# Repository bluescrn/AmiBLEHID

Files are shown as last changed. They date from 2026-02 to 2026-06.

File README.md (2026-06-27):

# AmiBLEHID

Work in progress. v0.3 PCB works. v0.4 is experimental+untested.

First prototype, before addition of buttons+LEDs:

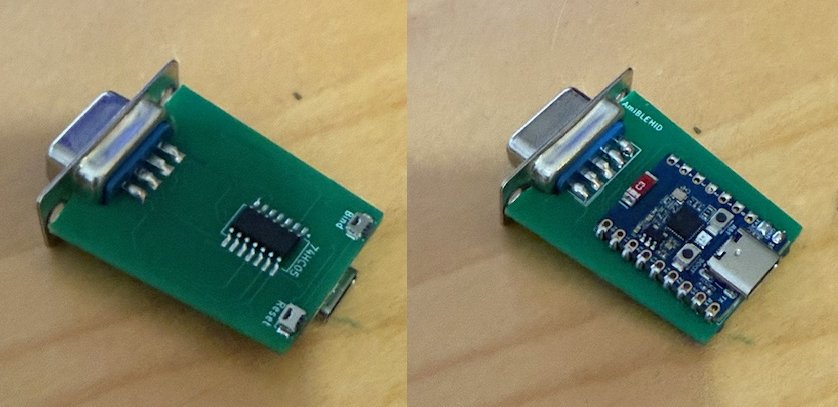
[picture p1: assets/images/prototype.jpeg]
Pic of prototype


## What is it?

With minimal other components (essentially just a 74HC05 and the joystick port connector), an ESP32-H2 module can be connected to an Amiga joystick/mouse port, and allow a BLE mouse or controller to be used with the Amiga.

The H2 has no wifi, and only supports BLE (no Bluetooth Classic). Other ESP32 modules likely draw too much current (With the Waveshare ESP32-H2-Zero and my initial code, I measured 20-23mA with am mouse connected, and 26mA while scanning)

There is an existing project, [Unijoysticle](https://github.com/ricardoquesada/unijoysticle2), that uses an ESP32-WROOM32 and provides compatibility with far more devices by supporting Bluetooth Classic, but it's a relatively bulky board and requires external power. This is an attempt to build a smaller neater 'dongle' using the same approach, albeit with more limited functionality.

## Features

- Mouse speed control (cycle 5 levels via button on board, or hold middle mouse button)
- Mouse emulation using right analog stick when using a controller and Amiga joystick port 1
- 'Up-to-jump' mode - Maps the 2nd button to joystick up

## Code

The code side of things is based around [NimBLE Arduino](https://docs.arduino.cc/libraries/nimble-arduino/) and [this HID report parsing code](https://github.com/pasztorpisti/hid-report-parser), and can be built in the Arduino IDE

Had to add a little bodge to the HID parser to read the hat switch (d-pad) properly, as the neutral position of a hat switch (usually 0 or -1 depending on device) is outside the logical_min/max range of the axis, and the parser was ignoring out-of-range values.

## Limitations

BLE game controllers are very uncommon, the only common+good ones that I'm aware of are the latest model of Xbox controller and the 8BitDo Ultimate Wireless 2.
  
Only supports two joystick/mouse buttons. Investigating

The USB-C port on the ESP32 module isn't currently supported for wired mice/controllers. Would be nice to support wired controllers, but the additional current draw is likely to be too much for the Amiga joystick port

## Tested+Compatible devices

Controllers:
- Xbox Series S/X controller (this is the version with USB-C and the extra 'share' button in the centre. Previous versions aren't BLE)
- 8BitDo Ultimate 2 Wireless

Mice:
- KeyChron M3 Wireless Mouse
- Logitech MX Anywhere 3
- Razer Atheris

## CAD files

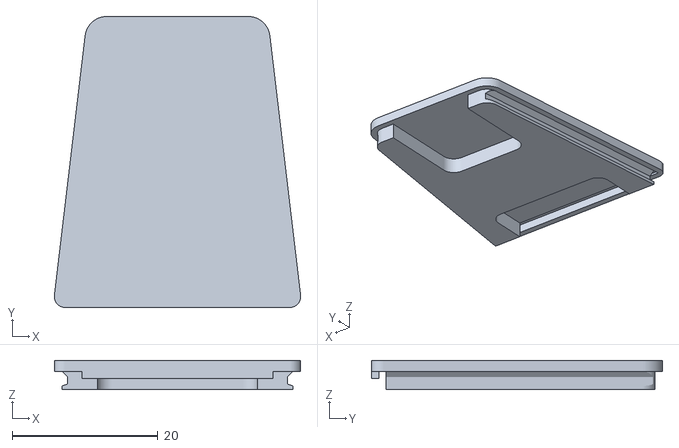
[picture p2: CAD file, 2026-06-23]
STLs/AmiBLEHID_Case_Upper.stl
33.9 x 40.0 x 4.00

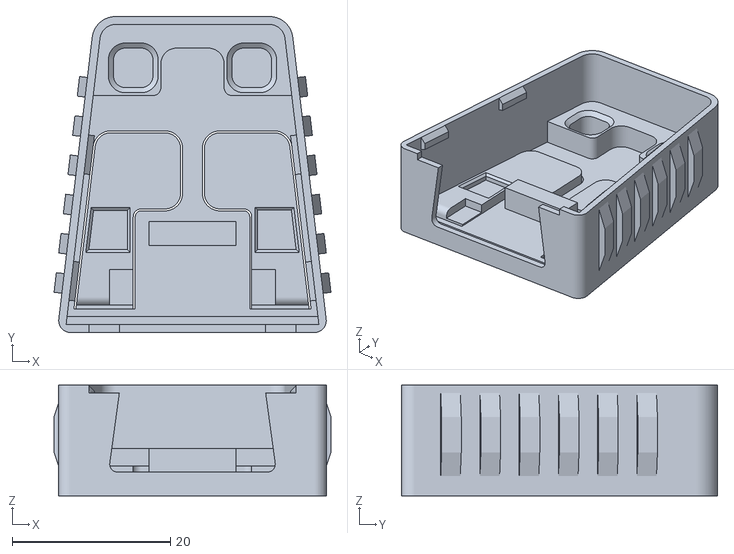
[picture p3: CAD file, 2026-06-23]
STLs/AmiBLEHID_Case_Lower.stl
35.1 x 40.0 x 14.0

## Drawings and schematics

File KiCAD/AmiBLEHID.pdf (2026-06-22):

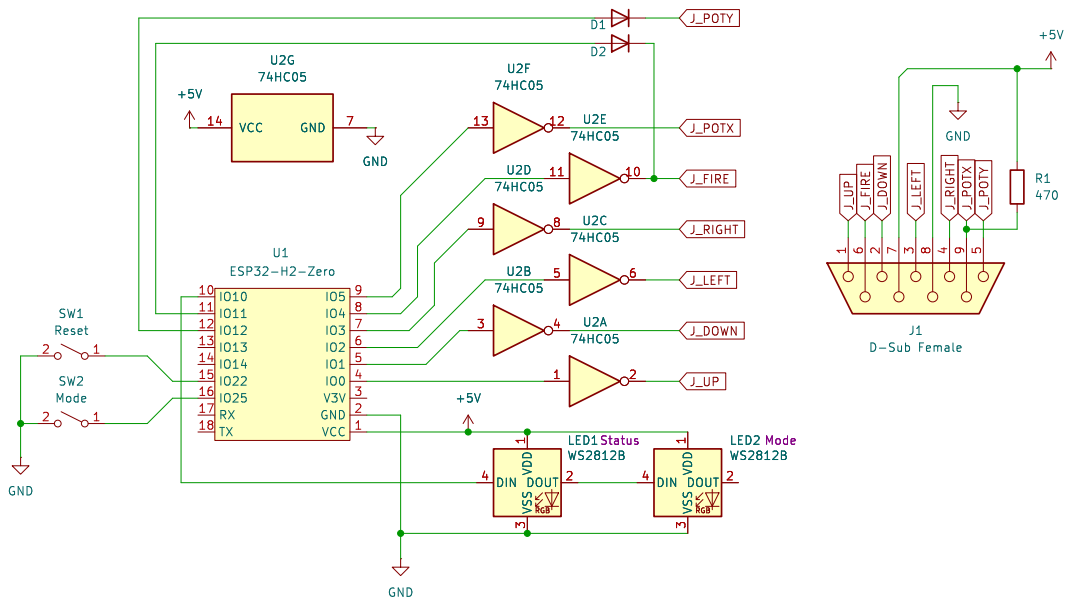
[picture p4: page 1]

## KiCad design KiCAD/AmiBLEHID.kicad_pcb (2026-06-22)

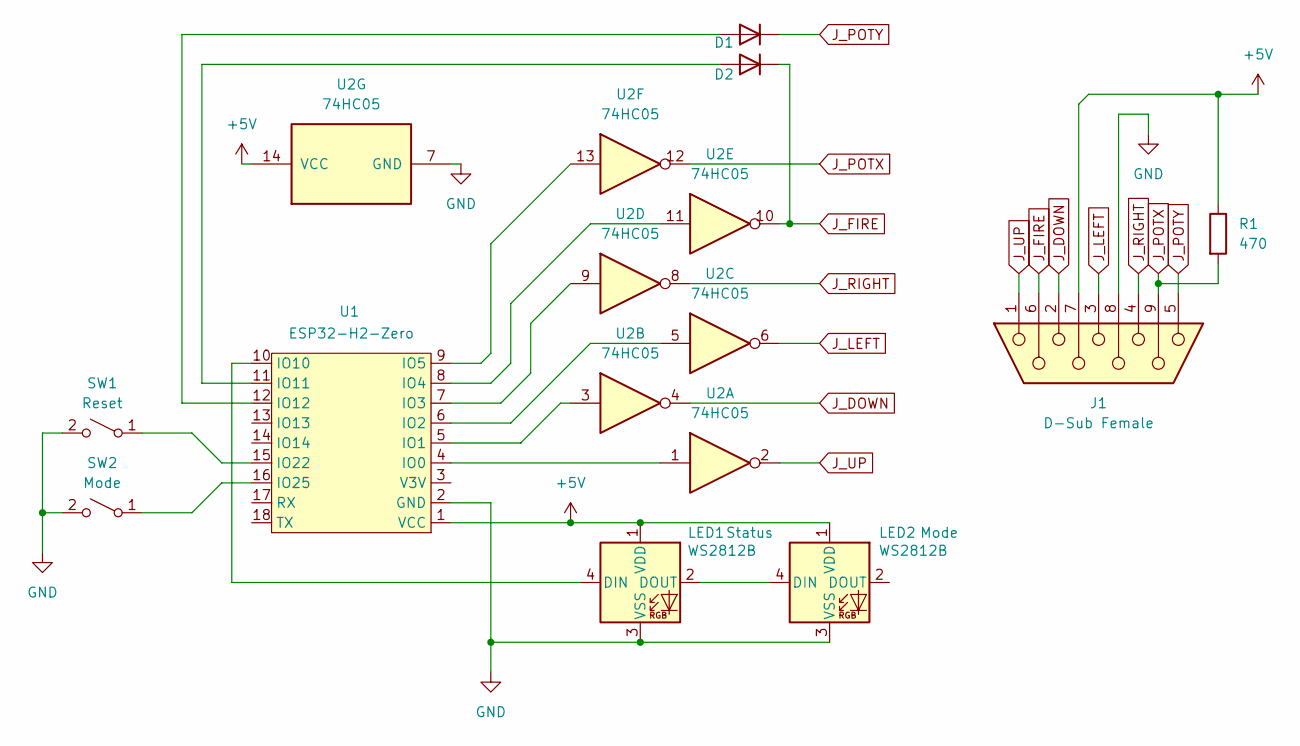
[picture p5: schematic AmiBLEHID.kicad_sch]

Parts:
D1, D2: 1N4148; D_1206_3216Metric
J1: D-Sub Female; DSUB-9_Socket_EdgeMount_P2.77mm
LED1, LED2: WS2812B; LED_WS2812B-Mini_PLCC4_3.5x3.5mm
R1: 470; R_1206_3216Metric
SW1: Reset; SW_SPST_PTS647_Sx50
SW2: Mode; SW_SPST_PTS647_Sx50
U1: ESP32-H2-Zero; Waveshare-ESP32-H2-Zero
U2: 74HC05; SO-14_5.3x10.2mm_P1.27mm

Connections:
+5V: J1.7, LED1.1 (VDD), LED2.1 (VDD), R1.1, U1.1 (VCC), U2.14 (VCC)
GND: J1.8, LED1.3 (VSS), LED2.3 (VSS), SW1.2 (B), SW2.2 (B), U1.2 (GND), U2.7 (GND)
J_DOWN: J1.2, U2.4
J_FIRE: D2.1 (K), J1.6, U2.10
J_LEFT: J1.3, U2.6
J_POTX: J1.9, R1.2, U2.12
J_POTY: D1.1 (K), J1.5
J_RIGHT: J1.4, U2.8
J_UP: J1.1, U2.2
unnamed: D1.2 (A), U1.12 (IO12)
unnamed: D2.2 (A), U1.11 (IO11)
unnamed: LED1.4 (DIN), U1.10 (IO10)
unnamed: LED1.2 (DOUT), LED2.4 (DIN)
unnamed: SW1.1 (A), U1.15 (IO22)
unnamed: SW2.1 (A), U1.16 (IO25)
unnamed: U1.4 (IO0), U2.1
unnamed: U1.5 (IO1), U2.3
unnamed: U1.6 (IO2), U2.5
unnamed: U1.7 (IO3), U2.9
unnamed: U1.8 (IO4), U2.11
unnamed: U1.9 (IO5), U2.13

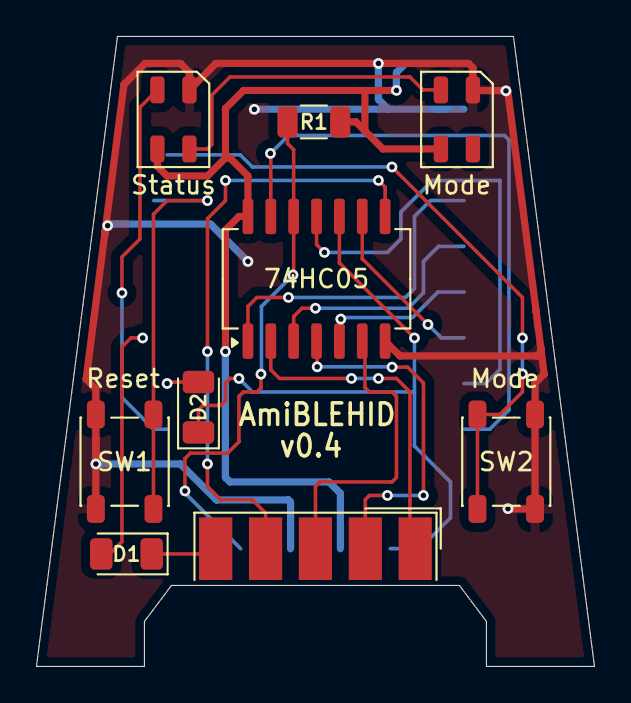
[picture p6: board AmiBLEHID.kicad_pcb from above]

Board: 2 copper layers, 31.0 x 35.0 mm, 10 parts (1 on the bottom side), 21 nets.

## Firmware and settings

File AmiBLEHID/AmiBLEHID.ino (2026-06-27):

// ------------------------------------------------------------------------------------------------------------------------
// AmiBLEHID
// - Connects a Bluetooth mouse or gamepad to Amiga joystick port.
//
// Intended for the WaveShare ESP32-H2-Mini, without outputs to joystick port connected via a 74HC05 open-collector hex inverter
//
// Board should be set to 'ESP32H2 Dev Module'
// Tools -> USB CDC on boot should be enabled to get serial console output
//
// Required libraries/packages:
// - NimBLE-Arduino - works with 2.5.0)
// - FastLED - works with with 3.10.3 (3.10.4 didn't work)
// - Works with esp32 board package 3.3.10
//
// Turn off Sketch->Optimize for debugging. Any performance gain might help with interrupt responsiveness for CD32 support?
// ------------------------------------------------------------------------------------------------------------------------

#define PIN_U           0
#define PIN_D           1
#define PIN_L           2
#define PIN_R           3
#define PIN_A           4
#define PIN_B           5

#define PIN_Y2          0
#define PIN_X1          1
#define PIN_Y1          2
#define PIN_X2          3

#define PIN_CD32_LATCH  12
#define PIN_CD32_CLOCK  11

#define PIN_BTN_RESET   22
#define PIN_BTN_MODE    25

#include <Arduino.h>
#include <NimBLEDevice.h>
#include <BTScan.h>
#include <BTHIDConn.h>
#include <Preferences.h>
#include <LEDs.h>

void IRAM_ATTR onQuadratureTimer();

// ------------------------------------------------------------------------------------------------------------------------
// States
// ------------------------------------------------------------------------------------------------------------------------

#define ANALOG_STICK_DEADZONE 64                // Analog sticks are scaled to a +/-256 range. Big deadzone/threshold when using for digital input
#define MOUSE_STICK_DEADZONE  40                // Smaller deadzone when using it for mouse

#define NUM_MOUSE_RATES       5

const int k_mouseRates[NUM_MOUSE_RATES] = {48, 64, 96, 160, 224};
const int k_defaultMouseRateIdx = 1;

const int k_hardResetHoldTime   = 140 * 3;      // works out at approx 3 secs. 

// ------------------------------------------------------------------------------------------------------------------------
// States
// ------------------------------------------------------------------------------------------------------------------------

enum State 
{
    State_Init,           // Initialising
    State_Scanning,       // Scanning for devices
    State_Connecting,     // Connecting
    State_Connected,      // Connected to a HID device
    State_Idle            // Scan timed out, no device found (wait for button to rescan)
};

enum GamepadMode
{
    Default,
    UpToJump,
    Invalid    
};


// ------------------------------------------------------------------------------------------------------------------------
// Main vars
// ------------------------------------------------------------------------------------------------------------------------

Preferences     _preferences;
BTScan*         _btScan                  = nullptr;
BTHIDConn*      _btHIDConn               = nullptr;
State           _state                   = State_Init;
int             _scanDuration            = 60*1000;

hw_timer_t     *_quadratureTimer         = NULL;
bool            _quadratureTimerStarted  = false;

int             _currMouseRateIdx        = 0;
GamepadMode     _currGamepadMode         = GamepadMode::Default;

LEDs            _statusLeds;
int             _resetHeldTimer          = 0;

volatile bool   _cd32Polling             = false;
volatile int    _cd32ButtonShiftRegister = 0;
volatile int    _cd32buttonState         = 0;
volatile int    _cd32ticksSincePolled    = 0;

int             _mouseDeltaX             = 0;
int             _mouseDeltaY             = 0;
int             _mouseRateX              = 0;
int             _mouseRateY              = 0;
int             _clampedMouseRateX       = 0;
int             _clampedMouseRateY       = 0;
int             _mouseQuadX              = 0;
int             _mouseQuadY              = 0;
int             _numQuadratureTicks      = 0;

const uint8_t   _quad0[4]                = {0,1,1,0};
const uint8_t   _quad1[4]                = {0,0,1,1};
const int       _quadCounterShiftDown    = 12;

// ------------------------------------------------------------------------------------------------------------------------
// Main setup function
// ------------------------------------------------------------------------------------------------------------------------

void setup ()
{    
    // Attempting to run the timer at much more than 6KHz causes it to break
    //
    // This corresponds to about 120 output state changes per frame at 50hz, and apparently the Amiga uses an internal 
    // counter with a limit of 128 counts per frame. I thought a 'count' would require a full pulse, but maybe it's a
    // state change, any of the four quadrature phases?
    
    _quadratureTimer = timerBegin(6000);
    timerAttachInterrupt(_quadratureTimer, &onQuadratureTimer);
    timerAlarm(_quadratureTimer, 1, true, 0);
    timerStart(_quadratureTimer);
    _quadratureTimerStarted = true;
    
    pinMode( PIN_U, OUTPUT );
    pinMode( PIN_D, OUTPUT );
    pinMode( PIN_L, OUTPUT );
    pinMode( PIN_R, OUTPUT );
    pinMode( PIN_A, OUTPUT );
    pinMode( PIN_B, OUTPUT );

    pinMode( PIN_BTN_RESET, INPUT_PULLUP );
    pinMode( PIN_BTN_MODE,  INPUT_PULLUP );

    pinMode( PIN_CD32_LATCH, INPUT_PULLUP );
    pinMode( PIN_CD32_CLOCK, INPUT_PULLUP );

    setupInterrupts();
    
    zeroOutputs();

    Serial.begin(115200);
    
    delay(500);

    _statusLeds.init();

    // Give serial monitor a chance to connect
    delayWithLEDUpdates( 1000 );
    
    Serial.println("");
    Serial.println("");
    Serial.println("");
    Serial.println("----------------------------------------");
    Serial.println("AmiBLEHID");
    Serial.println("----------------------------------------");
    loadSettings();
    Serial.println("Starting NimBLE Client");    
    Serial.println("");
  
    _btScan = new BTScan();
    _btScan->enableBinding( NimBLEDevice::getNumBonds()==0 );
    _btScan->start(_scanDuration);

    _btHIDConn = new BTHIDConn();

    _state = State_Scanning;
}



// ------------------------------------------------------------------------------------------------------------------------
// Delay, but calling LED update function every 16ms
// ------------------------------------------------------------------------------------------------------------------------

int _millisUntilLEDUpdate = 0;

void delayWithLEDUpdates( int millis )
{
    if ( _millisUntilLEDUpdate<millis )
    {
        FastLED.delay( _millisUntilLEDUpdate );
        millis-=_millisUntilLEDUpdate;
        _millisUntilLEDUpdate = 16;
        _statusLeds.process();
    }
    
    while( millis>16 )
    {
        FastLED.delay( 16 );
        _statusLeds.process();
        millis-=16;
        _millisUntilLEDUpdate = 16;
    }

    FastLED.delay(millis);
    _millisUntilLEDUpdate -= millis;    
}



// ------------------------------------------------------------------------------------------------------------------------
// Load settings from prefs store
// ------------------------------------------------------------------------------------------------------------------------

void loadSettings()
{
    _preferences.begin("AmiBLEHID", true);

    _currMouseRateIdx = _preferences.getUInt("MouseRate",   k_defaultMouseRateIdx );
    _currGamepadMode  = (GamepadMode)_preferences.getUInt("GamepadMode", 0 );

    if ( _currMouseRateIdx > NUM_MOUSE_RATES )
    {
         _currMouseRateIdx = 0;
    }    

    _preferences.end();
    saveSettings();
}

// ------------------------------------------------------------------------------------------------------------------------
// Save settings to prefs store
// ------------------------------------------------------------------------------------------------------------------------

void saveSettings()
{
    _preferences.begin("AmiBLEHID", false);

    Serial.printf("Save Settings: Mouse Rate %d, Gamepad Mode %d\n", _currMouseRateIdx, _currGamepadMode );

    _preferences.putUInt( "MouseRate",   _currMouseRateIdx );
    _preferences.putUInt( "GamepadMode", _currGamepadMode );

    _preferences.end();
}



// ------------------------------------------------------------------------------------------------------------------------
// Main loop
// ------------------------------------------------------------------------------------------------------------------------

void loop ()
{        
    switch( _state )
    {
        case State_Scanning:
            {
                // Blink on-board LED blue
                bool binding = _btScan->isBindingEnabled();
                _statusLeds.setState(LED_STATUS, binding ? LEDMODE_BTBIND : LEDMODE_BTSCAN);
                _statusLeds.setState(LED_MODE,   LEDMODE_OFF);
                zeroOutputs();
                
                // Found a device yet?
                const NimBLEAdvertisedDevice* foundDevice = _btScan->getDeviceToConnect();

                if ( foundDevice )
                {
                    Serial.println("Device found, attempting to connect!");

                    _statusLeds.setState(LED_STATUS, LEDMODE_BTCONNECTING);                 
                    delayWithLEDUpdates(16);

                    if ( _btHIDConn->connect(foundDevice) )
                    {
                        _state = State_Connecting;
                    }            
                    else
                    {
                        Serial.println("Failed to connect, resuming scan!");                        
                        _btScan->start( _scanDuration, true );
                    }
                }            
                else if (!_btScan->isScanning())
                {
                    _state = State_Idle;
                }
            }
            break;

        case State_Connecting:
            {                
                if ( _btHIDConn->isConnected() )
                {                
                    _state = State_Connected;
                }
            }

            break;

        case State_Connected:
            {
                if ( !_btHIDConn->isConnected() )
                {
                    zeroOutputs();
                    _statusLeds.setState(LED_STATUS, LEDMODE_DISCONNECTED); 
                    _statusLeds.setState(LED_MODE,   LEDMODE_DISCONNECTED);
                    delayWithLEDUpdates(500);

                    _state = State_Scanning;
                    Serial.println("Connection lost, restarting scan!");
                    _btScan->enableBinding( NimBLEDevice::getNumBonds()==0 );
                    _btScan->start( _scanDuration, false );
                }
                else
                {
                    if ( _btHIDConn->isGamepad() )
                    {
                        update_gamepad();               
                    }

                    if ( _btHIDConn->isMouse() )
                    {
                        update_mouse();
                    }
                }
            }

            break;

        case State_Idle:
            _statusLeds.setState(LED_STATUS, LEDMODE_IDLE);
            _statusLeds.setState(LED_MODE,   LEDMODE_OFF);
            break;
    }        

    // 3ms delay, refresh approx 4x per 60hz frame. Bluetooth will be the limiting factor
    delayWithLEDUpdates(3);

    if ( digitalRead(PIN_BTN_RESET)==0 )
    {
        _resetHeldTimer++;
    }

    if ( _resetHeldTimer>0 && (digitalRead(PIN_BTN_RESET)!=0) || _resetHeldTimer > k_hardResetHoldTime )
    {                        
        _btHIDConn->disconnect();
        _btScan->stop();
        
        
        if ( _resetHeldTimer > k_hardResetHoldTime )
        {    
            _statusLeds.setState(LED_STATUS, LEDMODE_HARDRESET);
            _statusLeds.setState(LED_MODE,   LEDMODE_HARDRESET);        
            delayWithLEDUpdates(750);

            while ( digitalRead(PIN_BTN_RESET)==0 )
            {
                delayWithLEDUpdates(10);
            }

            Serial.println("Reset button held, clearing bonds, restarting scan!");                            
            _btHIDConn->deleteAllBonds();                        
        }
        else
        {
            _statusLeds.setState(LED_STATUS, LEDMODE_DISCONNECTED);
            _statusLeds.setState(LED_MODE,   LEDMODE_DISCONNECTED);        
            delayWithLEDUpdates(750);

            int numBonds = NimBLEDevice::getNumBonds();            
            Serial.printf("Reset button, restarting scan (%d bonds)\n", NimBLEDevice::getNumBonds() );                                                    
        }                    

        _state = State_Scanning;        
        _btScan->enableBinding ( true );
        _btScan->start( _scanDuration, false );            
        _resetHeldTimer = 0;
    }    

}


// ------------------------------------------------------------------------------------------------------------------------
// Check for held input used to change modes
// ------------------------------------------------------------------------------------------------------------------------

bool _prevModeDecButton = false;
bool _prevModeIncButton = false;

int modeCycleCheck( bool decButton, bool incButton )
{
    int dir = 0;

    if ( incButton && !_prevModeIncButton )    
    {
        dir = 1;
    }

    if ( decButton && !_prevModeDecButton )
    {
        dir = 1;
    }

    _prevModeDecButton = decButton;
    _prevModeIncButton = incButton;

    return dir;
}


// ------------------------------------------------------------------------------------------------------------------------
// Gamepad Update
// ------------------------------------------------------------------------------------------------------------------------

// This was an attempt to minimize the impact of interrupt latency by shifting the data bits out in a tight
// loop within this ISR rather than trigger another interrupt from the clock pin. Don't think it's made a lot
// of difference though, as jittery latency on the triggering of this ISR can throw off the timing
//#define CD32_SHIFT_POLLING

static void IRAM_ATTR cd32_latch_isr(void *arg)
{
    if ( !digitalRead( PIN_CD32_LATCH ) )
    {                   
        // Must zero this pin as it's the clock input
        digitalWrite(PIN_A, 0);

        // Copy button state to shift reg var, output first bit
        digitalWrite(PIN_B, _cd32buttonState&1 );

        _cd32ButtonShiftRegister = _cd32buttonState>>1;                
        _cd32Polling             = true;
        _cd32ticksSincePolled    = 0;

#ifdef CD32_SHIFT_POLLING        
        // Loop until all bits haev been shifted out, or uintil our failsafe counter hits zero. 
        int  failsafe  = 500;
        int  shiftBits = 6;
        bool prevClock = false;
        
        while(failsafe>0 && shiftBits>0)
        {
            failsafe--;
            bool clock = digitalRead(PIN_CD32_CLOCK);
            if ( prevClock !=clock )
            {
                if ( !clock )
                {
                    digitalWrite(PIN_B, (_cd32ButtonShiftRegister&1) );         
                    _cd32ButtonShiftRegister>>=1;
                    shiftBits--;                    
                }

                prevClock = clock;
            }
        }        
#endif

    }
    else
    {
        // Restore standard button state        
        digitalWrite(PIN_B, (_cd32buttonState&1) ? 1 : 0 );
        digitalWrite(PIN_A, (_cd32buttonState&2) ? 1 : 0 );
        _cd32Polling = false;
    }     
}

static void IRAM_ATTR cd32_clock_isr( void* arg )
{        
    digitalWrite(PIN_B, (_cd32ButtonShiftRegister&1) );         
    _cd32ButtonShiftRegister>>=1;
}


void setupInterrupts()
{
    // Using ESP-IDF functions to set up ISRs may reduce latency slightly over the Arduino wrapper
    gpio_install_isr_service( ESP_INTR_FLAG_LEVEL3 );

    gpio_config_t io_conf;
    io_conf.pin_bit_mask = (1ULL << (gpio_num_t)PIN_CD32_LATCH);
    io_conf.mode         = GPIO_MODE_INPUT;  
    io_conf.pull_down_en = GPIO_PULLDOWN_DISABLE;
    io_conf.pull_up_en   = GPIO_PULLUP_ENABLE;
    io_conf.intr_type    = GPIO_INTR_ANYEDGE;
        
    gpio_config(&io_conf);    
    gpio_isr_handler_add((gpio_num_t)PIN_CD32_LATCH, cd32_latch_isr, NULL);

#ifndef CD32_SHIFT_POLLING
    io_conf.pin_bit_mask = (1ULL << (gpio_num_t)PIN_CD32_CLOCK);
    io_conf.mode         = GPIO_MODE_INPUT;  
    io_conf.pull_down_en = GPIO_PULLDOWN_DISABLE;
    io_conf.pull_up_en   = GPIO_PULLUP_ENABLE;
    io_conf.intr_type    = GPIO_INTR_NEGEDGE;
        
    gpio_config(&io_conf);    
    gpio_isr_handler_add((gpio_num_t)PIN_CD32_CLOCK, cd32_clock_isr, NULL);
#endif            
}
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

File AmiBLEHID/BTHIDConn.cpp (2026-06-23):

// ------------------------------------------------------------------------------------------------------------------------
// BTHIDConn.cpp
// Class to handle the current bluetooth HID connection
//
// Initially based on this example: https://github.com/esp32beans/BLE_HID_Client
// ------------------------------------------------------------------------------------------------------------------------

#include <Arduino.h>
#include <NimBLEDevice.h>
#include <BTHIDConn.h>

//#define FULL_LOGGING

// Main scanner class
// ========================================================================================================================

class BTClientCallbacks : public NimBLEClientCallbacks 
{
private:

    bool m_isConnected = false;


    void onConnect(NimBLEClient* pClient) override
    {
        Serial.println("Connected");

        // After connection we should change the parameters if we don't need fast response times.
        // These settings are 150ms interval, 0 latency, 450ms timout.
        // Timeout should be a multiple of the interval, minimum is 100ms.
        // I find a multiple of 3-5 * the interval works best for quick response/reconnect.
        // Min interval: 120 * 1.25ms = 150, Max interval: 120 * 1.25ms = 150, 0 latency, 60 * 10ms = 600ms timeout
        //pClient->updateConnParams(120,120,0,60);

        m_isConnected = true;
    };

    void onDisconnect(NimBLEClient* pClient, int reason) override 
    {
        Serial.printf("%s Disconnected, reason = %d\n", pClient->getPeerAddress().toString().c_str(), reason);
        m_isConnected = false;
    };

    // Called when the peripheral requests a change to the connection parameters.
    // Return true to accept and apply them or false to reject and keep the currently used parameters. Default will return true.
    // (Failing to accepts parameters may result in the remote device disconnecting?)
    bool onConnParamsUpdateRequest(NimBLEClient* pClient, const ble_gap_upd_params* params) 
    {        
        return true;
    };

    // Security handled here - Note: these are the same return values as defaults
    uint32_t onPassKeyRequest()
    {
        Serial.println("Client Passkey Request");
        return 123456;
    };

    bool onConfirmPIN(uint32_t pass_key)
    {
        Serial.print("The passkey YES/NO number: ");
        Serial.println(pass_key);
        // Return false if passkeys don't match
        return true;
    };

    // Pairing process complete, we can check the results in ble_gap_conn_desc
    void onAuthenticationComplete(ble_gap_conn_desc* desc)
    {
        if(!desc->sec_state.encrypted) 
        {
            Serial.println("Encrypt connection failed - disconnecting");
            // Find the client with the connection handle provided in desc
            NimBLEDevice::getClientByHandle(desc->conn_handle)->disconnect();
            return;
        }
    };


public:   

    bool isConnected()
    {
        return m_isConnected;
    }
};


// Main scanner class
// ========================================================================================================================

// ------------------------------------------------------------------------------------------------------------------------
// Constructor
// ------------------------------------------------------------------------------------------------------------------------

BTHIDConn::BTHIDConn()
{
    m_clientCallbacks = new BTClientCallbacks();
}


// ------------------------------------------------------------------------------------------------------------------------
// Destructor
// ------------------------------------------------------------------------------------------------------------------------

BTHIDConn::~BTHIDConn()
{
    if ( m_clientCallbacks!=nullptr )
    {
        delete m_clientCallbacks;
        m_clientCallbacks = nullptr;
    }
}


// ------------------------------------------------------------------------------------------------------------------------
// Notification handler callback
// ------------------------------------------------------------------------------------------------------------------------

void BTHIDConn::notifyCB(NimBLERemoteCharacteristic* pRemoteCharacteristic, uint8_t* pData, size_t length, uint8_t reportId, bool isNotify)
{        
    int res = m_parser.Parse(pData, length, reportId);

    m_stateValid = true;

    if ( isMouse() )
    {
        m_mouseDeltaX += m_mouseAxes[hid::MouseConfig::X];
        m_mouseDeltaY += m_mouseAxes[hid::MouseConfig::Y];
    }
      
#ifdef FULL_LOGGING      
    Serial.printf( "HID reportId %d, parseResult %d, Data: ", reportId,res );
    for (size_t i = 0; i < length; i++) 
    {
        Serial.print(pData[i], HEX);
        Serial.print(',');
    }
    Serial.println();     
#endif    
}


// ------------------------------------------------------------------------------------------------------------------------
// isConnected
// ------------------------------------------------------------------------------------------------------------------------

bool BTHIDConn::isConnected()
{
    if (m_clientCallbacks)
    {
        return m_clientCallbacks->isConnected();
    }

    return false;
}

// ------------------------------------------------------------------------------------------------------------------------
// deleteAllBonds
// ------------------------------------------------------------------------------------------------------------------------

void BTHIDConn::deleteAllBonds()
{
    NimBLEAddress bondedAddresses[NIMBLE_MAX_CONNECTIONS];
    
    NimBLEDevice::deleteAllBonds();

    int numBonds = NimBLEDevice::getNumBonds();

    if (numBonds>0)
    {
        Serial.printf("NimBLEDevice::deleteAllBonds() left %d bonds present\n", numBonds );

        for( int i=0; i<numBonds;i++ )
        {
            bondedAddresses[i] = NimBLEDevice::getBondedAddress(i);
        }

        for( int i=0; i<numBonds;i++ )
        {            
            bool success = NimBLEDevice::deleteBond(bondedAddresses[i]);

            if ( !success )
            {
                // Can't delete bonds while still connected/scanning. That's the most likely cause if this happens again
                Serial.printf("Failed to delete bond %d: %s\n", i, bondedAddresses[i].toString().c_str()  );
            }
        }
    }
}

// ------------------------------------------------------------------------------------------------------------------------
// connect
// ------------------------------------------------------------------------------------------------------------------------
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

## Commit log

2026-02-15 Pic of prototype
2026-04-26 WIP - Updates for new iteration with WS2812 LEDs
    [AmiBLEHID-B_Cu.gbl, AmiBLEHID-B_Mask.gbs, AmiBLEHID-B_Silkscreen.gbo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]
2026-06-22 Code updates. Better binding/reset logic, and scaling of analog/hat axis ranges so it works with 8BitDo Ultimate 2 as well as Xbox controller
    [AmiBLEHID.ino, BTHIDConn.cpp, BTScan.cpp]
2026-06-22 KiCAD project updates - *untested* 0.4 revision aimed at enabling CD32 protocol support
    [AmiBLEHID-B_Cu.gbl, AmiBLEHID-B_Mask.gbs, AmiBLEHID-B_Silkscreen.gbo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]
2026-06-23 Mouse emulation via right analog stick on controller. Also map left/right bumpers to Amiga buttons 1+2 (for use along with right stick as mouse buttons)
2026-06-23 Printable case STLs
    [AmiBLEHID_Case_Lower.stl, AmiBLEHID_Case_Upper.stl]
2026-07-03 Tweak to schematic, just cleaner layout, couple of photos, tweak to status LED output on connection failure
2026-07-04 Attempt to speed up ISR for CD32 protocol. Doesn't really seem to have helped. There's got to be higher-priority interrupts delaying our GPIO interrupts.
2026-07-05 Respond to positive edge of CD32 clock, gives fractionally more time for interrupt to set the output bit
2026-07-05 CD32 protocol example trace
2026-07-20 CD32 protocol - shift out a zero then a one after the 7 bits for the buttons. Makes it work with JoyPortTest. Also output mouse wheel and MMB presses using CD32 protocol (no Amiga driver to use this 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
2026-07-24 Experimental mouse wheel driver based on TankMouse driver
2026-10-10 v0.5 PCB layout, more compact design to fit A600
